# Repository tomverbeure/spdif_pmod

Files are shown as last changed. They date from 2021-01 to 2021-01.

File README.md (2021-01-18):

# S/PDIF Optical Output PMOD

* [My blog post about this project](http://tomverbeure.github.io/2021/01/18t/SPDIF-Output-PMOD.html)

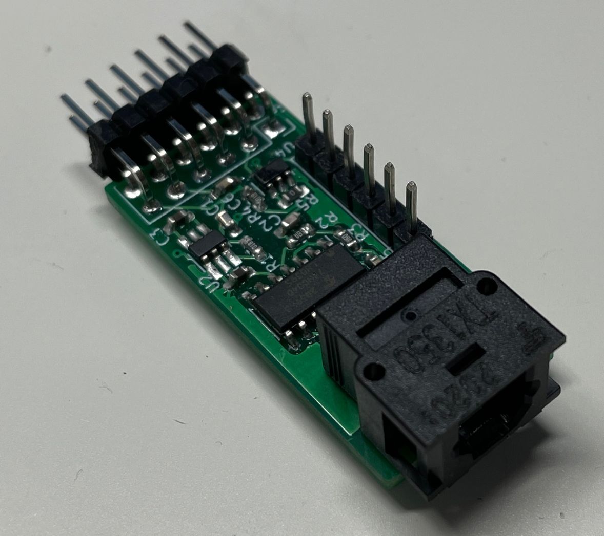
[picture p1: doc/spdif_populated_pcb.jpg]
S/PDIF Populatd PCB


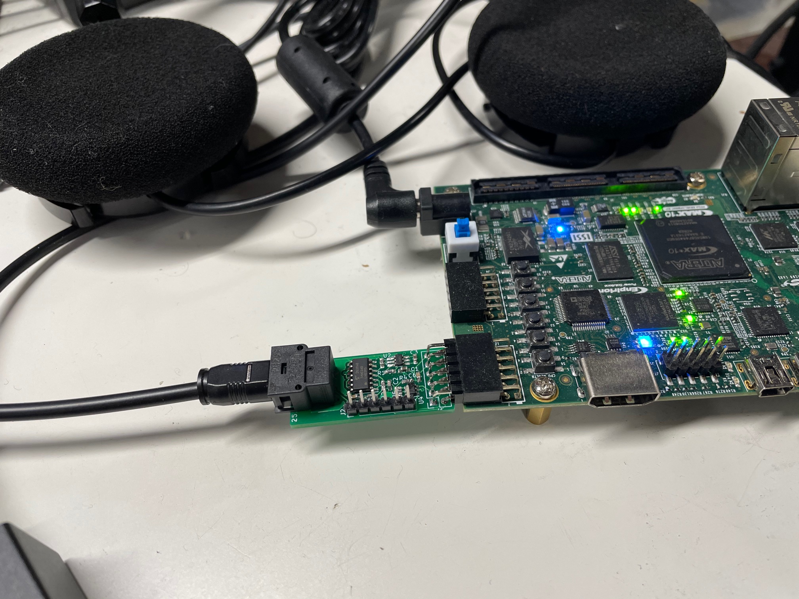
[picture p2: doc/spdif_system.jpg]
S/PDIF System


Features:

* S/PDIF optical output (TOSLINK)
* 4 GPIOs

The total cost is around ~$30:

* PCB (JLCPCB): $2 + $14 shipping (for 5 PCBs)
* TOSLink connecter: $10
* All the rest: ~$4

## SPDIF Board

The board was designed with [KiCAD](https://kicad.org/).

**Schematic**

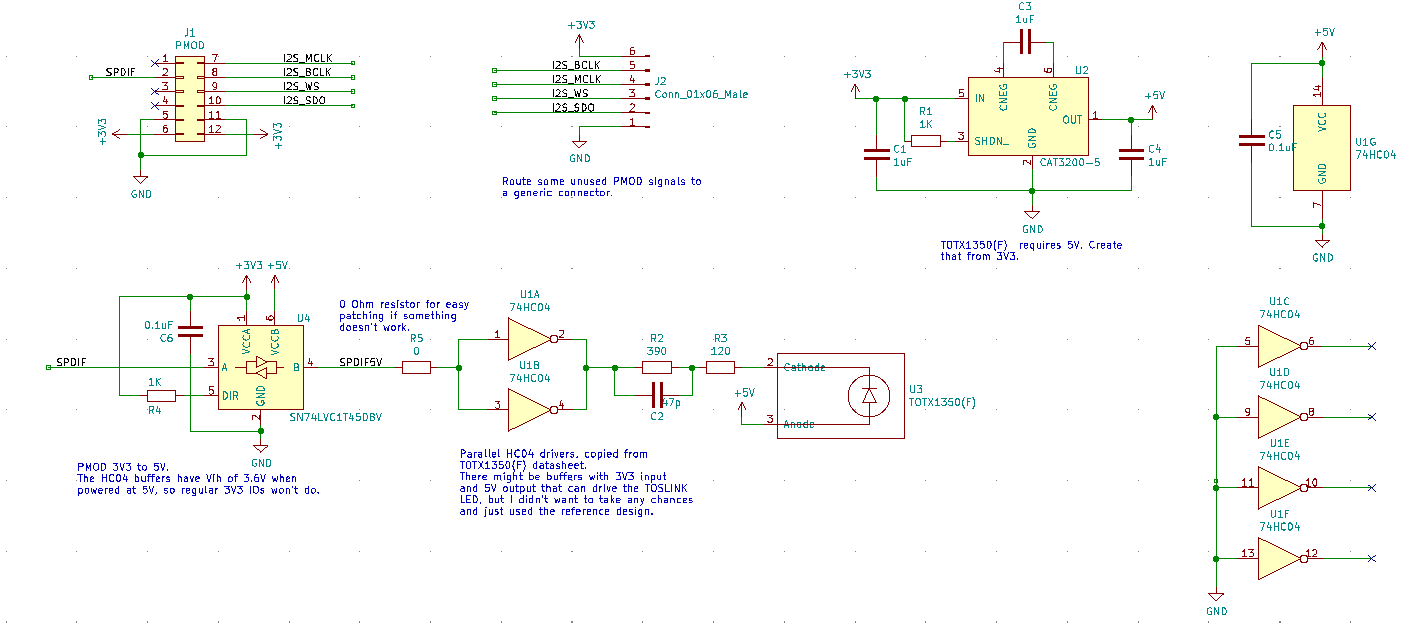
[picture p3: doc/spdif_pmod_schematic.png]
S/PDIF PMOD Schematic


[Schematic in PDF format](pcb/pmod_spdif/pmod_spdif.pdf)

**PCB**

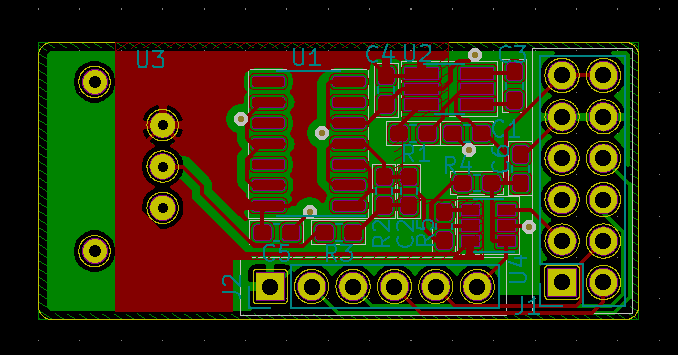
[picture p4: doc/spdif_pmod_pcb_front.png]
S/PDIF PMOD PCB


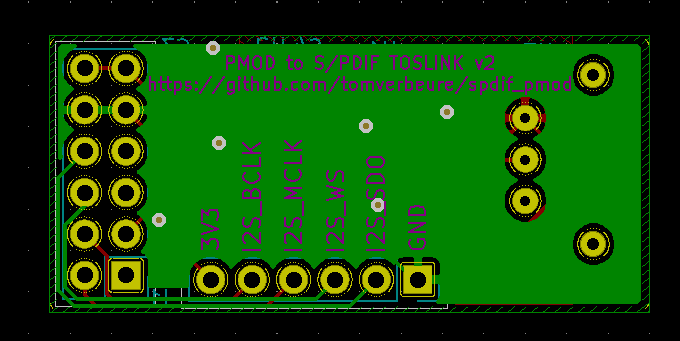
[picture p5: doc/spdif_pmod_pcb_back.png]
S/PDIF PMOD PCB


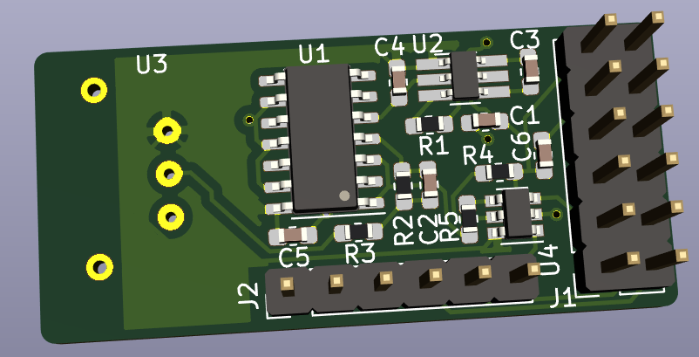
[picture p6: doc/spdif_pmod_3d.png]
S/PDIF PMOD PCB 3D


**Component list**

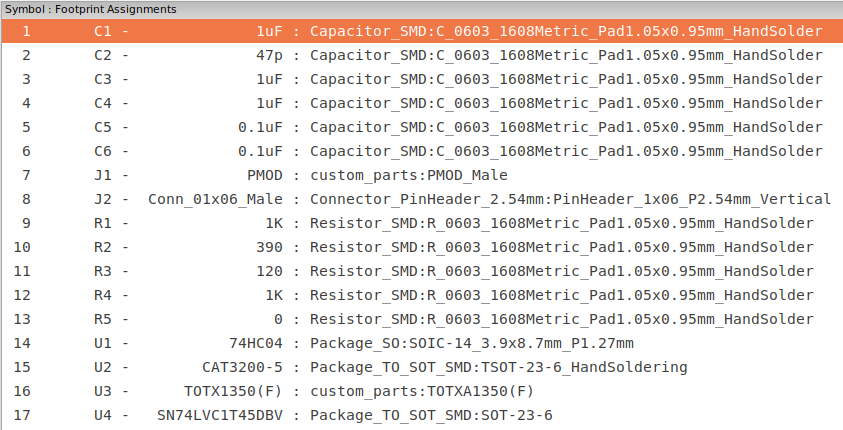
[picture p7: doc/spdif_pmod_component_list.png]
S/PDIF PMOD Components


## Example Design

The PMOD was tested on an [Intel Max10 development board](https://www.intel.com/content/www/us/en/programmable/products/boards_and_kits/dev-kits/altera/max-10-fpga-development-kit.html), 
but it should be trivial to make it work on any FPGA board that has a PMOD connector.

The [RTL](blob/main/fpga/spinal/src/main/scala/spdif/SpdifOut.scala) is written in 
[SpinalHDL](https://spinalhdl.github.io/SpinalDoc-RTD/), which gets converted into Verilog.

There's also a small [testbench](tree/main/fpga/tb/spdif) that uses 
[CXXRTL](https://tomverbeure.github.io/2020/08/08/CXXRTL-the-New-Yosys-Simulation-Backend.html) 
to simulate the whole thing. The testbench is not self-checking. You'll need to eyeball the waveforms to verify
that things are working...

The Max10 design uses a PLL to create a 6.144MHz clock out of the 50MHz oscillator clock.

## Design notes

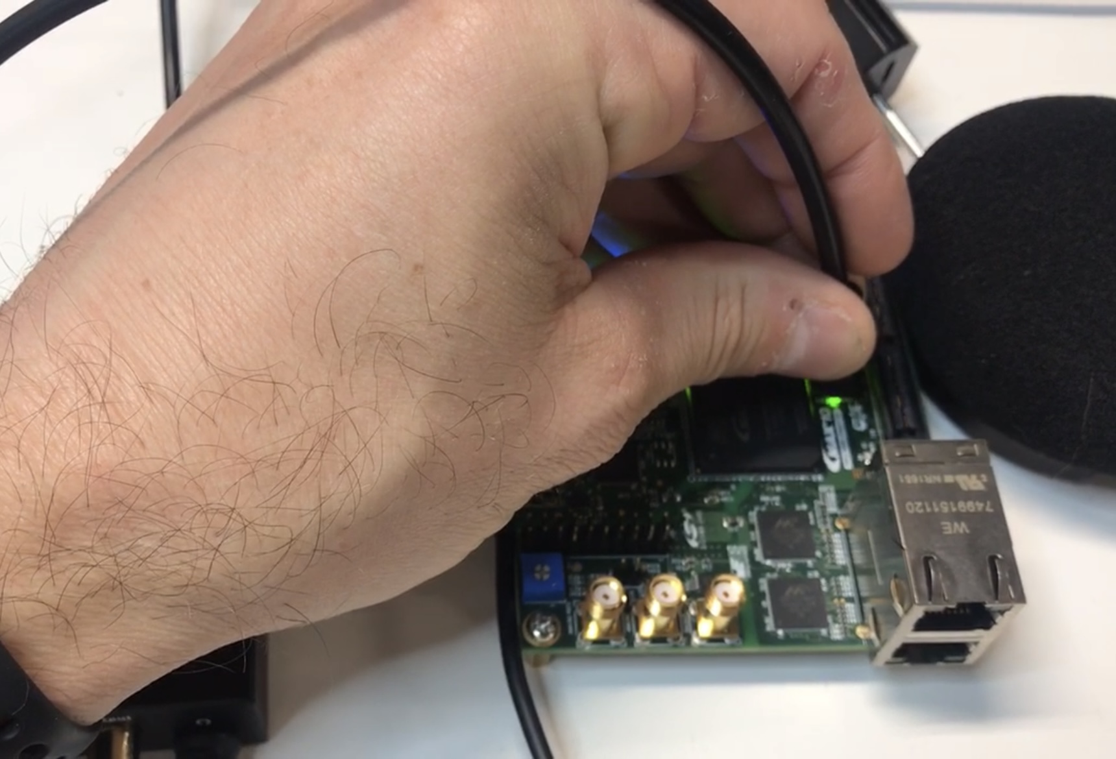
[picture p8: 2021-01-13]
doc/holding_cable_above_led.jpg

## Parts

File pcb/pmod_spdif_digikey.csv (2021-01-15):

# | QUANTITY | PART NUMBER | MANUFACTURER PART NUMBER | DESCRIPTION | CUSTOMER REFERENCE | BACKORDER | UNIT PRICE | EXTENDED PRICE
1 | 2 | 1528-2445-ND | 3661 | MINIBOOST 5V AP3602A |  | 0 | 2.95000 | 5.90
2 | 5 | CAT3200TDI-GT3OSCT-ND | CAT3200TDI-GT3 | IC REG CHARGE PUMP 5V TSOT23 |  | 0 | 1.49000 | 7.45
3 | 100 | 399-C0603C105K9PAC7411CT-ND | C0603C105K9PAC7411 | CAP CER 1UF 6.3V X5R 0603 |  | 0 | 0.02860 | 2.86
4 | 100 | 478-06036C104KAT4ACT-ND | 06036C104KAT4A | CAP CER 0.1UF 6.3V X7R 0603 |  | 0 | 0.01620 | 1.62
5 | 5 | 74HC04DCT-ND | 74HC04D | IC INVERTER 6CH 6-INP 14SOIC |  | 0 | 0.35000 | 1.75
6 | 5 | TOTX1350(F)-ND | TOTX1350(F) | FIBER OPTIC XMITTER 650NM |  | 0 | 10.45000 | 52.25
7 | 10 | 296-52713-1-ND | SN74AVC1T45DBVRE4 | IC TRNSLTR BIDIRECTIONAL SOT23-6 |  | 0 | 0.52900 | 5.29

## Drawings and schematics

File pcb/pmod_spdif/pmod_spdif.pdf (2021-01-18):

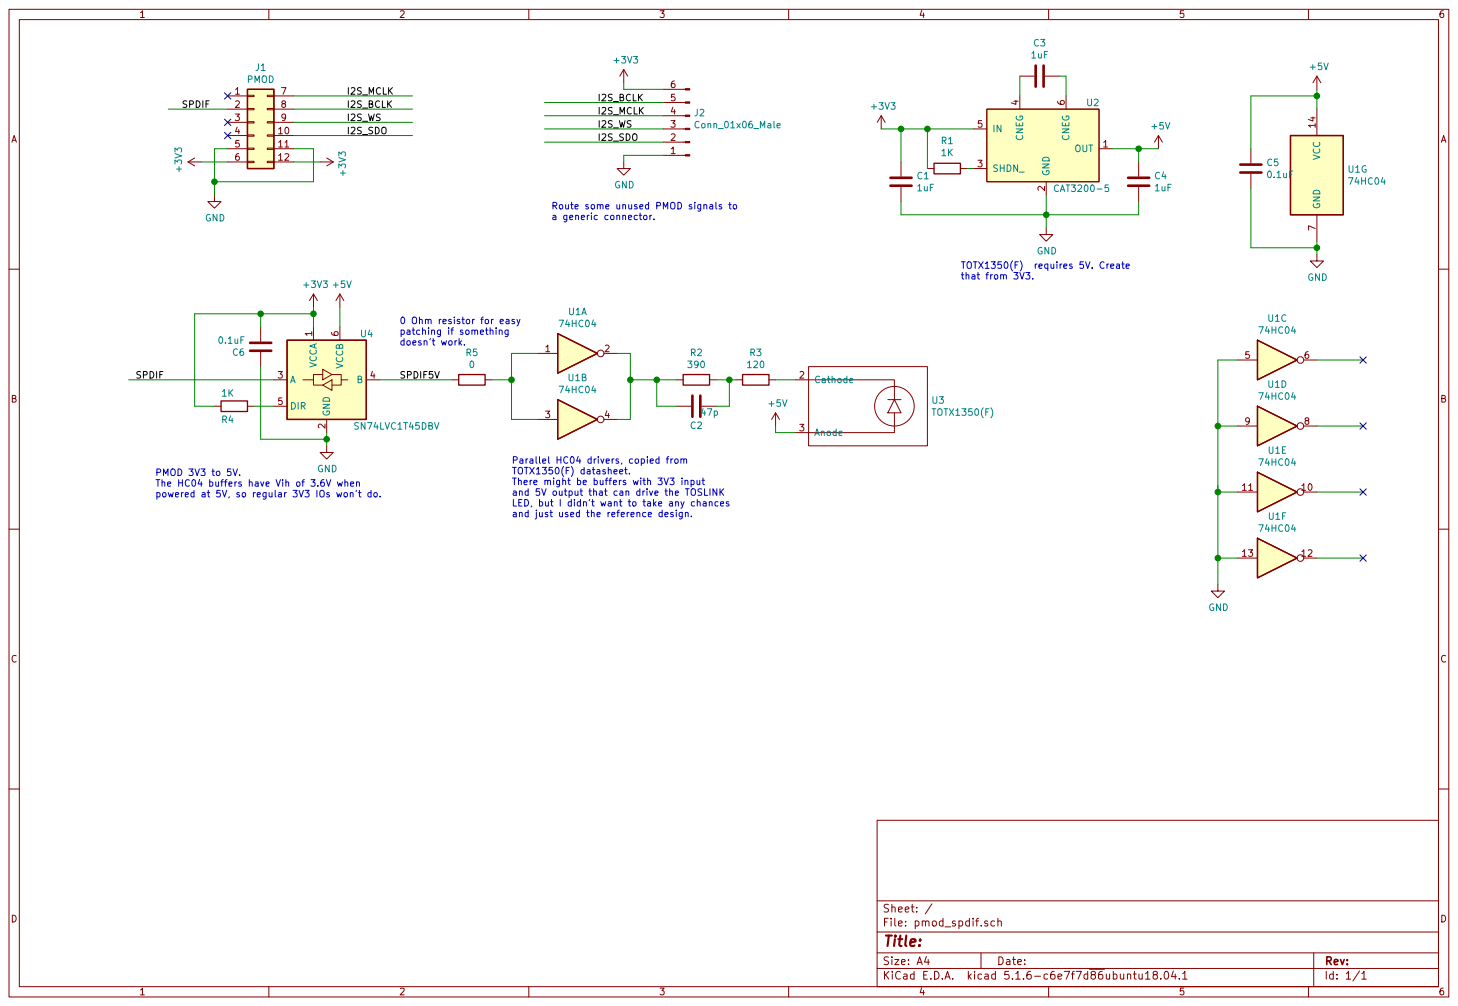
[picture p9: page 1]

Route some unused PMOD signals to
a generic connector.

that from 3V3. PMOD 3V3 to 5V. The HC04 buffers have Vih of 3.6V when powered at 5V, so regular 3V3 IOs won't do.

0 Ohm resistor for easy

TOTX1350(F) datasheet.
There might be buffers with 3V3 input
and 5V output that can drive the TOSLINK
LED, but I didn't want to take any chances
and just used the reference design.

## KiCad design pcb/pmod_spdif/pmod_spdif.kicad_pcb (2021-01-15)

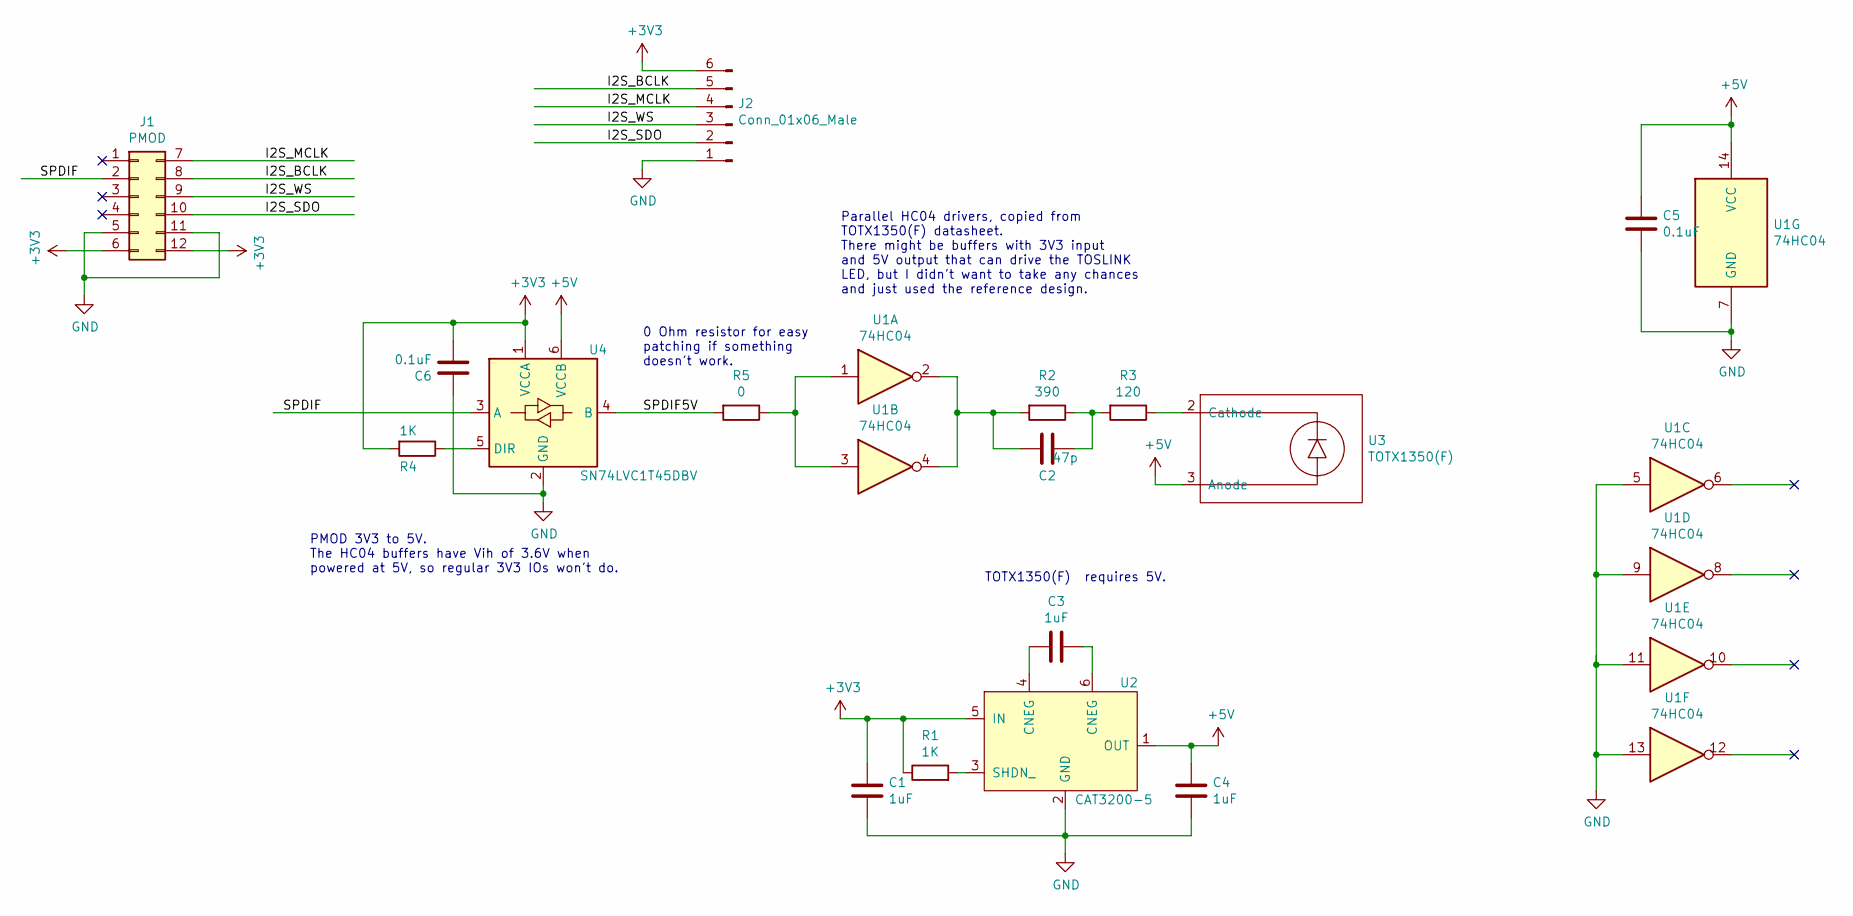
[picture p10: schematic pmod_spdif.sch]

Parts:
C1, C3, C4: 1uF; C_0603_1608Metric_Pad1.05x0.95mm_HandSolder
C2: 47p; C_0603_1608Metric_Pad1.05x0.95mm_HandSolder
C5, C6: 0.1uF; C_0603_1608Metric_Pad1.05x0.95mm_HandSolder
J1: PMOD; PMOD_Male
J2: Conn_01x06_Male; PinHeader_1x06_P2.54mm_Vertical
R1, R4: 1K; R_0603_1608Metric_Pad1.05x0.95mm_HandSolder
R2: 390; R_0603_1608Metric_Pad1.05x0.95mm_HandSolder
R3: 120; R_0603_1608Metric_Pad1.05x0.95mm_HandSolder
R5: 0; R_0603_1608Metric_Pad1.05x0.95mm_HandSolder
U1: 74HC04; SOIC-14_3.9x8.7mm_P1.27mm
U2: CAT3200-5; TSOT-23-6_HandSoldering
U3: TOTX1350(F); TOTXA1350(F)
U4: SN74LVC1T45DBV; SOT-23-6

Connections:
+3V3: C1.1, C6.2, J1.6, J1.12, J2.6, R1.1, R4.2, U2.5 (IN), U4.1 (VCCA)
+5V: C4.1, C5.1, U1.14 (VCC), U2.1 (OUT), U3.3 (Anode), U4.6 (VCCB)
/I2S_BCLK: J1.8, J2.5
/I2S_MCLK: J1.7, J2.4
/I2S_SDO: J1.10, J2.2
/I2S_WS: J1.9, J2.3
/SPDIF: J1.2, U4.3 (A)
/SPDIF5V: R5.2, U4.4 (B)
GND: C1.2, C4.2, C5.2, C6.1, J1.5, J1.11, J2.1, U1.5, U1.7 (GND), U1.9, U1.11, U1.13, U2.2 (GND), U4.2 (GND)
unnamed: C2.1, R2.2, U1.2, U1.4
unnamed: C2.2, R2.1, R3.2
unnamed: C3.1, U2.6 (CNEG)
unnamed: C3.2, U2.4 (CNEG)
unnamed: R1.2, U2.3 (SHDN_)
unnamed: R3.1, U3.2 (Cathode)
unnamed: R4.1, U4.5 (DIR)
unnamed: R5.1, U1.1, U1.3

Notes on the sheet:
Parallel HC04 drivers, copied from TOTX1350(F) datasheet. There might be buffers with 3V3 input and 5V output that can drive the TOSLINK LED, but I didn't want to take any chances and just used the reference design.
0 Ohm resistor for easy patching if something doesn't work.
TOTX1350(F) requires 5V.
PMOD 3V3 to 5V. The HC04 buffers have Vih of 3.6V when powered at 5V, so regular 3V3 IOs won't do.

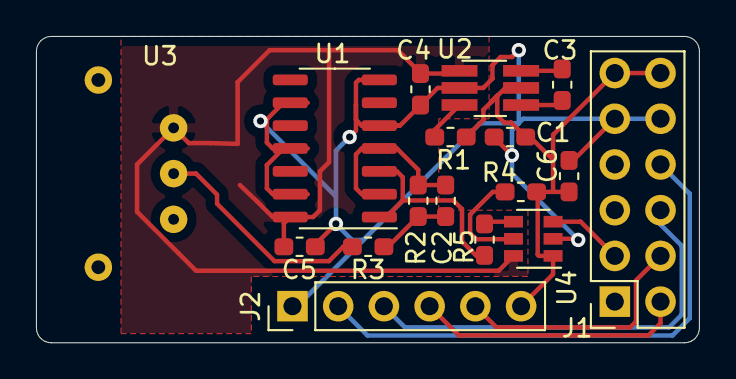
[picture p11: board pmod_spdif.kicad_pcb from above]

Board: 2 copper layers, 36.8 x 17.0 mm, 17 parts (0 on the bottom side), 17 nets.

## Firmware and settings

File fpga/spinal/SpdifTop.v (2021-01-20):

// Generator : SpinalHDL v1.3.5    git head : f0505d24810c8661a24530409359554b7cfa271a
// Date      : 19/01/2021, 15:39:36
// Component : SpdifTop


module SpdifOut (
      output  io_spdif,
      output  io_audio_samples_rdy,
      input  [15:0] io_audio_samples_0,
      input  [15:0] io_audio_samples_1,
      input   clk_spdif,
      input   clk_spdif_reset_);
  reg [15:0] _zz_SpdifOut_4_;
  wire  _zz_SpdifOut_5_;
  wire  _zz_SpdifOut_6_;
  wire [0:0] _zz_SpdifOut_7_;
  wire [5:0] _zz_SpdifOut_8_;
  wire [0:0] _zz_SpdifOut_9_;
  wire [7:0] _zz_SpdifOut_10_;
  wire [0:0] _zz_SpdifOut_11_;
  wire [7:0] _zz_SpdifOut_12_;
  wire [31:0] _zz_SpdifOut_13_;
  wire [4:0] _zz_SpdifOut_14_;
  wire  _zz_SpdifOut_15_;
  wire  _zz_SpdifOut_16_;
  reg  clk_div_cntr_willIncrement;
  wire  clk_div_cntr_willClear;
  reg [0:0] clk_div_cntr_valueNext;
  reg [0:0] clk_div_cntr_value;
  wire  clk_div_cntr_willOverflowIfInc;
  wire  clk_div_cntr_willOverflow;
  reg  time_slot_cntr_willIncrement;
  wire  time_slot_cntr_willClear;
  reg [5:0] time_slot_cntr_valueNext;
  reg [5:0] time_slot_cntr_value;
  wire  time_slot_cntr_willOverflowIfInc;
  wire  time_slot_cntr_willOverflow;
  reg  subframe_cntr_willIncrement;
  wire  subframe_cntr_willClear;
  reg [0:0] subframe_cntr_valueNext;
  reg [0:0] subframe_cntr_value;
  wire  subframe_cntr_willOverflowIfInc;
  wire  subframe_cntr_willOverflow;
  reg  frame_cntr_willIncrement;
  wire  frame_cntr_willClear;
  reg [7:0] frame_cntr_valueNext;
  reg [7:0] frame_cntr_value;
  wire  frame_cntr_willOverflowIfInc;
  wire  frame_cntr_willOverflow;
  reg  audio_samples_rdy;
  reg [15:0] audio_samples_0;
  reg [15:0] audio_samples_1;
  wire [7:0] _zz_SpdifOut_1_;
  wire [7:0] b_preamble;
  wire [7:0] _zz_SpdifOut_2_;
  wire [7:0] m_preamble;
  wire [7:0] _zz_SpdifOut_3_;
  wire [7:0] w_preamble;
  wire [7:0] preamble;
  reg  spdif_out;
  wire [23:0] sample_data;
  wire  valid_flag_;
  wire  user_data;
  wire  channel_status;
  wire [26:0] non_parity_data;
  wire  parity;
  wire [31:0] output_data;
  function  zz_clk_div_cntr_willIncrement(input dummy);
    begin
      zz_clk_div_cntr_willIncrement = 1'b0;
      if(1'b1)begin
        zz_clk_div_cntr_willIncrement = 1'b1;
      end
    end
  endfunction
  wire  _zz_SpdifOut_17_;
  assign _zz_SpdifOut_5_ = (clk_div_cntr_value == (1'b0));
  assign _zz_SpdifOut_6_ = ((subframe_cntr_value == (1'b0)) && (time_slot_cntr_value == (6'b000000)));
  assign _zz_SpdifOut_7_ = time_slot_cntr_willIncrement;
  assign _zz_SpdifOut_8_ = {5'd0, _zz_SpdifOut_7_};
  assign _zz_SpdifOut_9_ = frame_cntr_willIncrement;
  assign _zz_SpdifOut_10_ = {7'd0, _zz_SpdifOut_9_};
  assign _zz_SpdifOut_11_ = (1'b0);
  assign _zz_SpdifOut_12_ = {7'd0, _zz_SpdifOut_11_};
  assign _zz_SpdifOut_13_ = (output_data >>> _zz_SpdifOut_14_);
  assign _zz_SpdifOut_14_ = (time_slot_cntr_value >>> 1);
  assign _zz_SpdifOut_15_ = ((((((((((non_parity_data[0] ^ non_parity_data[1]) ^ non_parity_data[2]) ^ non_parity_data[3]) ^ non_parity_data[4]) ^ non_parity_data[5]) ^ non_parity_data[6]) ^ non_parity_data[7]) ^ non_parity_data[8]) ^ non_parity_data[9]) ^ non_parity_data[10]);
  assign _zz_SpdifOut_16_ = non_parity_data[11];
  always @(*) begin
    case(subframe_cntr_value)
      1'b0 : begin
        _zz_SpdifOut_4_ = audio_samples_0;
      end
      default : begin
        _zz_SpdifOut_4_ = audio_samples_1;
      end
    endcase
  end

  assign _zz_SpdifOut_17_ = zz_clk_div_cntr_willIncrement(1'b0);
  always @ (*) clk_div_cntr_willIncrement = _zz_SpdifOut_17_;
  assign clk_div_cntr_willClear = 1'b0;
  assign clk_div_cntr_willOverflowIfInc = (clk_div_cntr_value == (1'b1));
  assign clk_div_cntr_willOverflow = (clk_div_cntr_willOverflowIfInc && clk_div_cntr_willIncrement);
  always @ (*) begin
    clk_div_cntr_valueNext = (clk_div_cntr_value + clk_div_cntr_willIncrement);
    if(clk_div_cntr_willClear)begin
      clk_div_cntr_valueNext = (1'b0);
    end
  end

  always @ (*) begin
    time_slot_cntr_willIncrement = 1'b0;
    if(clk_div_cntr_willOverflow)begin
      time_slot_cntr_willIncrement = 1'b1;
    end
  end

  assign time_slot_cntr_willClear = 1'b0;
  assign time_slot_cntr_willOverflowIfInc = (time_slot_cntr_value == (6'b111111));
  assign time_slot_cntr_willOverflow = (time_slot_cntr_willOverflowIfInc && time_slot_cntr_willIncrement);
  always @ (*) begin
    time_slot_cntr_valueNext = (time_slot_cntr_value + _zz_SpdifOut_8_);
    if(time_slot_cntr_willClear)begin
      time_slot_cntr_valueNext = (6'b000000);
    end
  end

  always @ (*) begin
    subframe_cntr_willIncrement = 1'b0;
    if(time_slot_cntr_willOverflow)begin
      subframe_cntr_willIncrement = 1'b1;
    end
  end

  assign subframe_cntr_willClear = 1'b0;
  assign subframe_cntr_willOverflowIfInc = (subframe_cntr_value == (1'b1));
  assign subframe_cntr_willOverflow = (subframe_cntr_willOverflowIfInc && subframe_cntr_willIncrement);
  always @ (*) begin
    subframe_cntr_valueNext = (subframe_cntr_value + subframe_cntr_willIncrement);
    if(subframe_cntr_willClear)begin
      subframe_cntr_valueNext = (1'b0);
    end
  end

  always @ (*) begin
    frame_cntr_willIncrement = 1'b0;
    if(subframe_cntr_willOverflow)begin
      frame_cntr_willIncrement = 1'b1;
    end
  end

  assign frame_cntr_willClear = 1'b0;
  assign frame_cntr_willOverflowIfInc = (frame_cntr_value == (8'b10111111));
  assign frame_cntr_willOverflow = (frame_cntr_willOverflowIfInc && frame_cntr_willIncrement);
  always @ (*) begin
    if(frame_cntr_willOverflow)begin
      frame_cntr_valueNext = (8'b00000000);
    end else begin
      frame_cntr_valueNext = (frame_cntr_value + _zz_SpdifOut_10_);
    end
    if(frame_cntr_willClear)begin
      frame_cntr_valueNext = (8'b00000000);
    end
  end
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

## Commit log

2021-01-15 pmod_spdif v2. Only cosmetic changes.
    [pmod_spdif-B_Cu.gbr, pmod_spdif-B_Mask.gbr, pmod_spdif-B_Paste.gbr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]
2021-01-15 Add digikey component list.
    [pmod_spdif_digikey.csv]
2021-01-18 Update documentation.
    [pmod_spdif.sch]
